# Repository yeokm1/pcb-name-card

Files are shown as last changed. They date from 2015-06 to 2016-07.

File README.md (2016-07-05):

# pcb-name-card

My name or business card that is on a Printed Circuit Board (PCB). Comes with an white LED, UV LED and a ruler. Not forgetting a QR code containing my contact details in [Vcard](https://en.wikipedia.org/wiki/VCard) format.

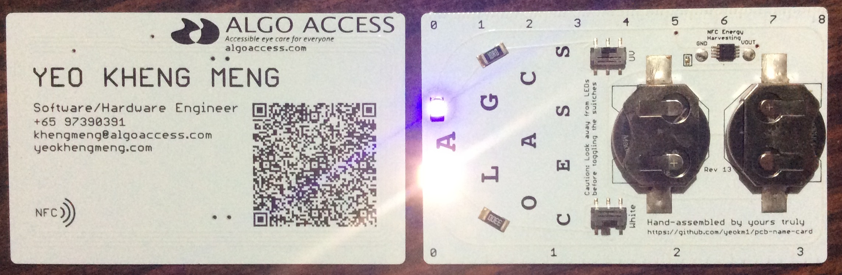
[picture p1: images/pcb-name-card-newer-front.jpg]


The lastest iteration of my name card is now in white.

I gave a talk on my name card, slides available in the picture link below.

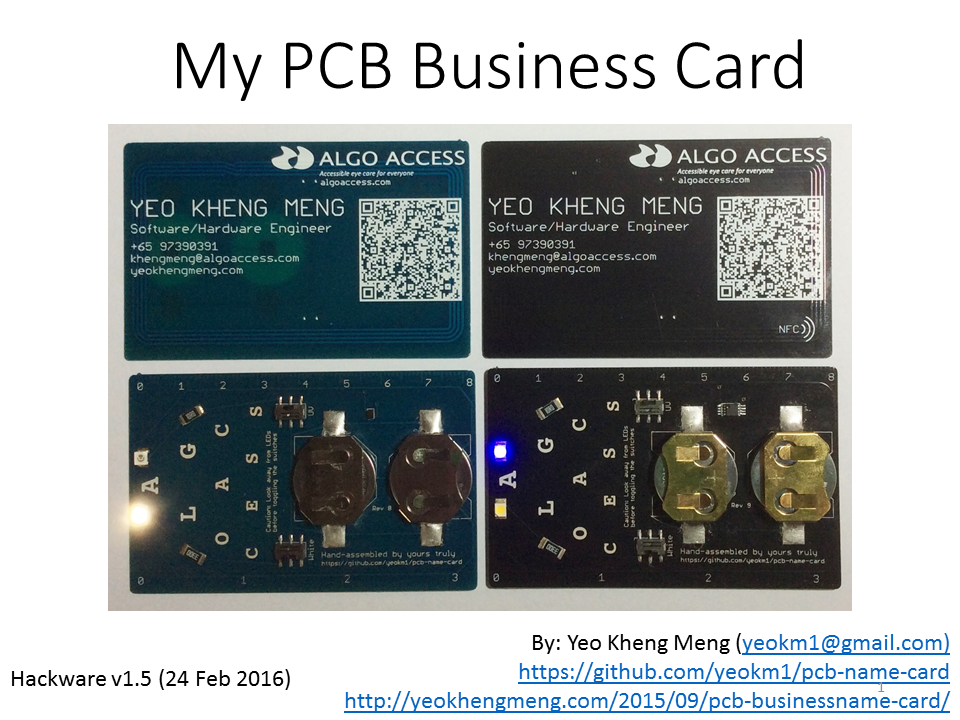
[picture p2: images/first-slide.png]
My slides on slideshare (http://www.slideshare.net/yeokm1/pcb-business-card)


###PCB Design software and addons/references used

1. Eagle 7.3.0: I use Standard but Light should still be able to open/modify the files.
2. Modified CR2032 library based on [here](https://github.com/nickaknudson/eagle-nickaknudson/blob/master/cr2032.lbr)
2. Elecrow Design Rule Check for 2 layers (in repo as `Elecrow_2-layer_eagle_rule.dru`)
3. Elecrow Gerber Generater 2-layer board (in repo as `Elecrow_Gerber_Generater_DrillAlign.cam`)
4. QR code generated from [here](http://goqr.me/)

###Schematic drawings

Images are exported from Eagle at 600dpi.

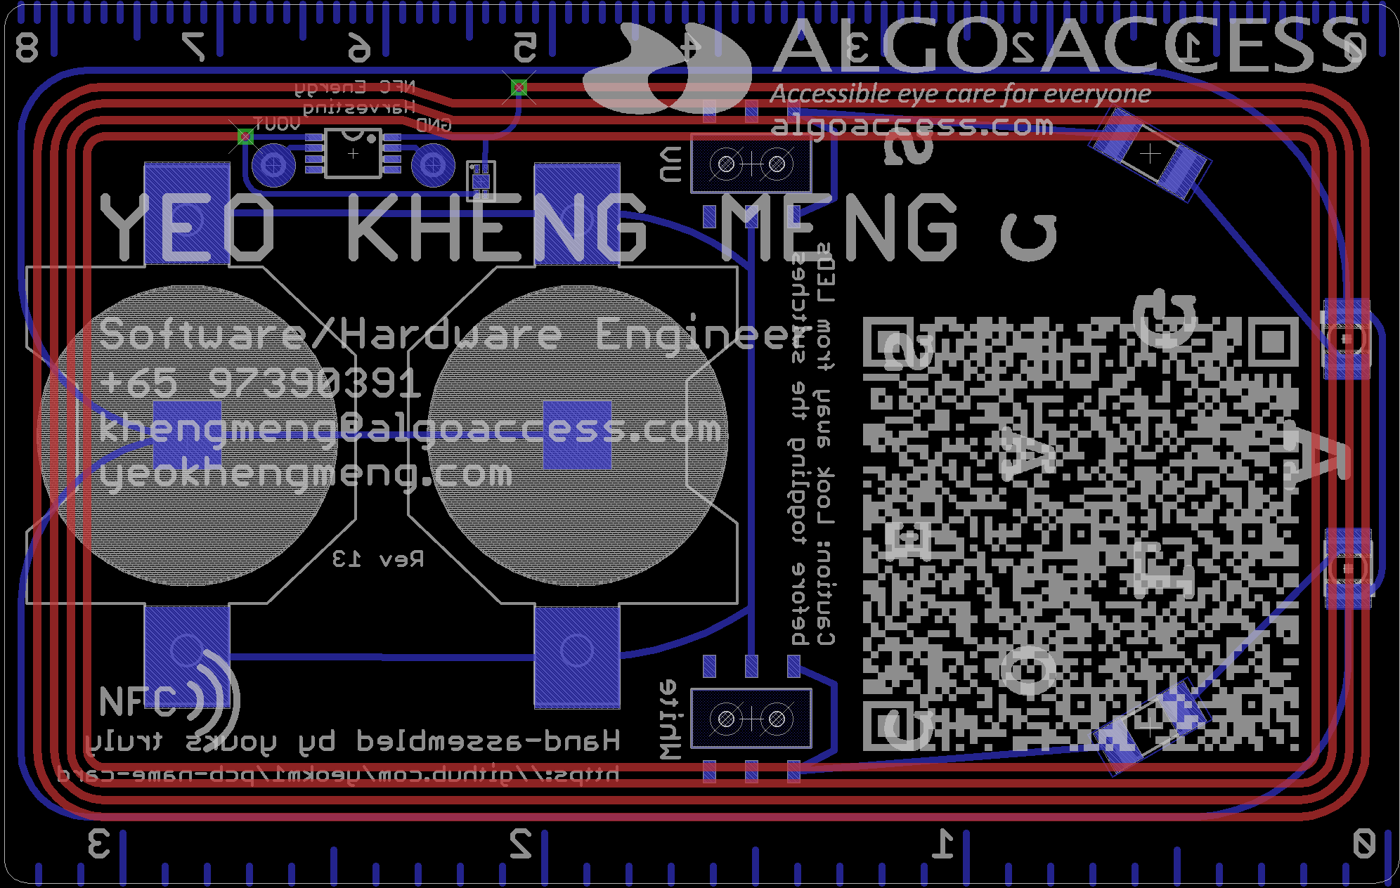
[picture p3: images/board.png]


The board layout as seen in Eagle.

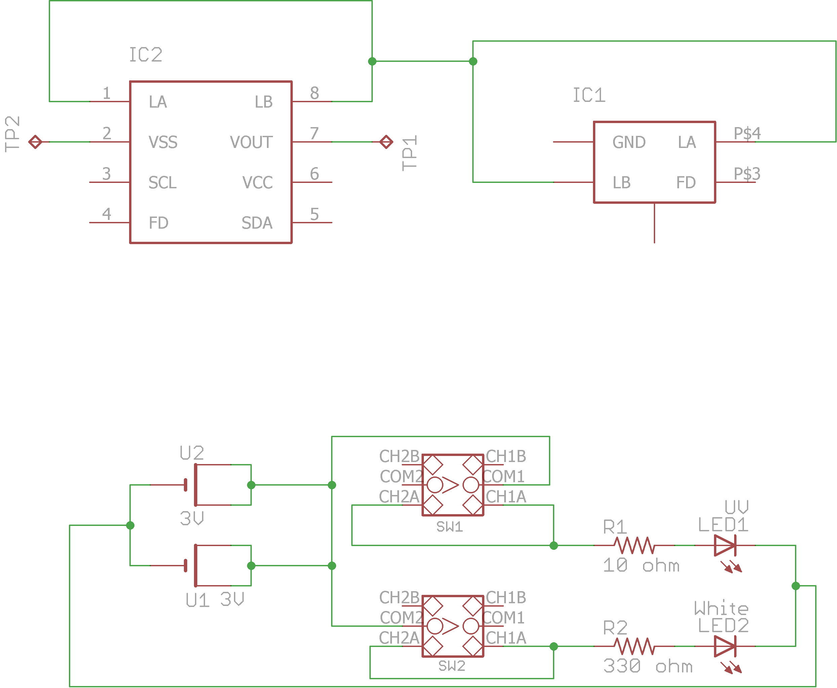
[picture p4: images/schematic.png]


The board schematic as seen in Eagle.

###Bill of Materials (BOM) for components only

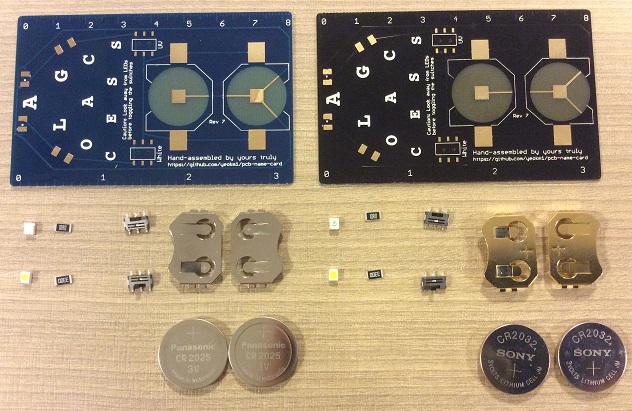
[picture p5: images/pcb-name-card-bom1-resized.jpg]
  
Components in their raw form

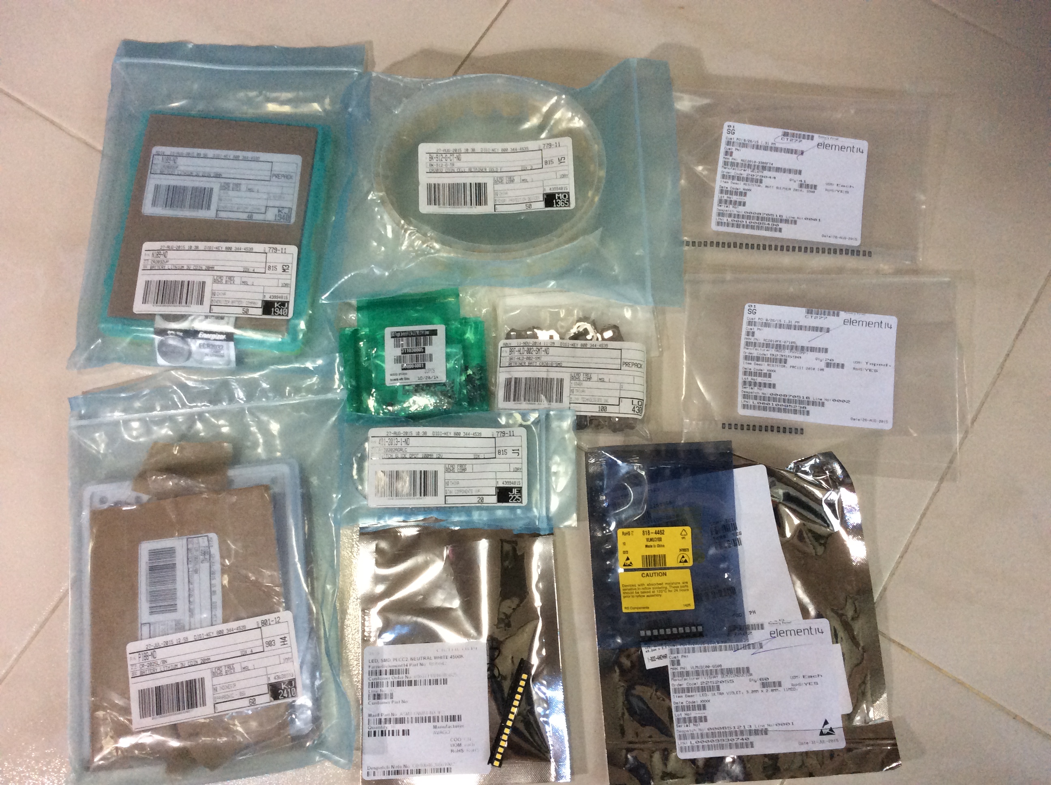
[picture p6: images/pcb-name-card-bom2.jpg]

Components still in their original packets from different suppliers.

Assume minimum order 10 pieces, cost in Singapore dollars. There are additional savings if I order more say 50 units but the savings are still small. Delivery for BOM not included.

The BOM is available in the odt spreadsheets in this repo.

###PCB fabrication

PCB fabrication is currently done by [Elecrow (10-pieces-link)](http://www.elecrow.com/10pcs-2-layer-pcb-p-1175.html) or [(50-pieces-link)](http://www.elecrow.com/50pcs-2-layer-pcb-enig-p-1172.html) based on the following settings. Remember to consult the order submission specifications at the bottom of the previous link before submitting. Use the provided Gerber generator to produce the Gerber files.

####My Fabrication Settings:

1. Layer: 2
2. PCB Thickness: 0.6mm
3. Copper Weight : 1oz 35um (NA for 50 pieces)
4. PCB Size : 10cm Max * 10cm Max (or 50cm2 for 50 pieces)
5. PCB Color : Blue or Black
6. Surface Finish: ENIG
7. PCB Stencil : NO Stencil
8. Lead time : Shipped in 4 to 7 days (NA for 50 pieces)
9. Panelizing : Single PCB with milling

###PCB Cost including delivery
Assume US$1 = SG$1.3

####Unit cost for 10 PCBs only
Total PCB Cost: US$30.80 + US$16.17 (DHL) = US$46.97  
Individual PCB Cost: (US$46.97 * 1.3) / 10 = SG$6.10  

####Unit cost for 50 PCBs only
Total PCB Cost: US$62.47 + US$18.81 (DHL) = US$81.28  
Individual PCB Cost: (US$81.28 * 1.3) / 50 = SG$2.11  

###Total Unit cost (SGD$) with components

| Pieces | Young Blue | Formal Black |
|---|---|---|
| 10 | $15.53 | $17.19 |
| 50 | $10.53 | $12.26 |

#References
1. [How to design a 13.56 MHz
customized tag antenna](http://www.st.com/st-web-ui/static/active/jp/resource/technical/document/application_note/CD00221490.pdf)
2. [The impact of high pulse drain on CR2032 coin-cell battery capacity](http://m.eet.com/media/1121454/c0924post.pdf)
3. [Panasonic NFC Design Navigator](http://www.semicon.panasonic.co.jp/en/tool/nfcdesignnavigator/)

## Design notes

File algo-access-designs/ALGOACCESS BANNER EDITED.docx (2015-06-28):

A

L G

O A C

C E S S

ALGO ACCESS PTE LTD

Accessible Eyecare for everyone

WEBSITE: www.algoaccess.com

EMAIL: info@algoaccess.com

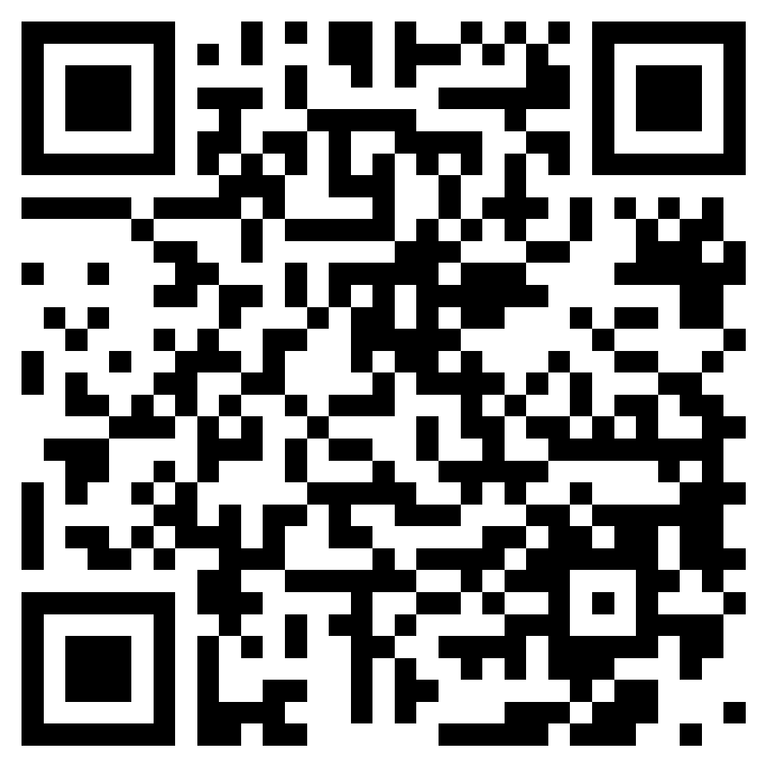
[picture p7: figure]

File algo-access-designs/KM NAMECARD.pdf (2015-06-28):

A
L G
O | A | C
C | E | S | S

## YEO KHENG MENG

WEBSITE: WWW.ALGOACCESS.COM EMAIL: KHENGMENG@ALGOACCESS.COM CONTACT NUMBER: +65 97390391

Accessible(eye(care(for(everyone(

ALGO ACCESS

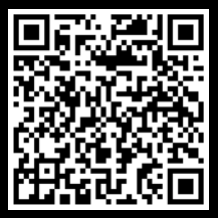
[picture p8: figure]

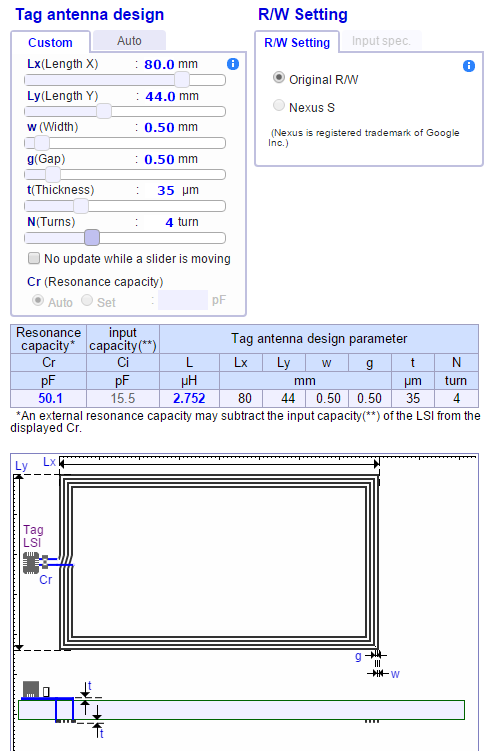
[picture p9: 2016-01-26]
images/tag-antenna-design.PNG

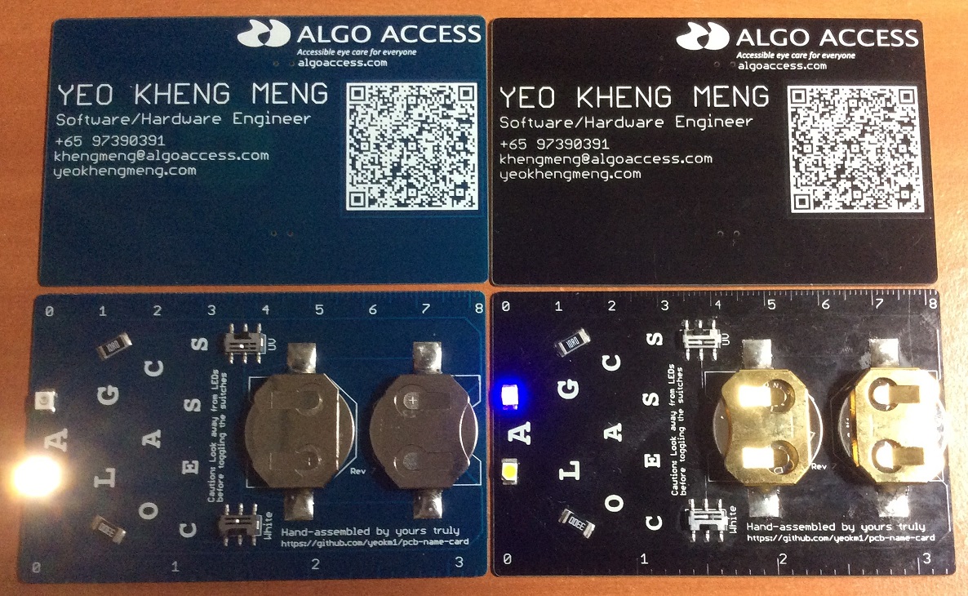
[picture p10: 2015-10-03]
images/pcb-name-card-main-resized.jpg

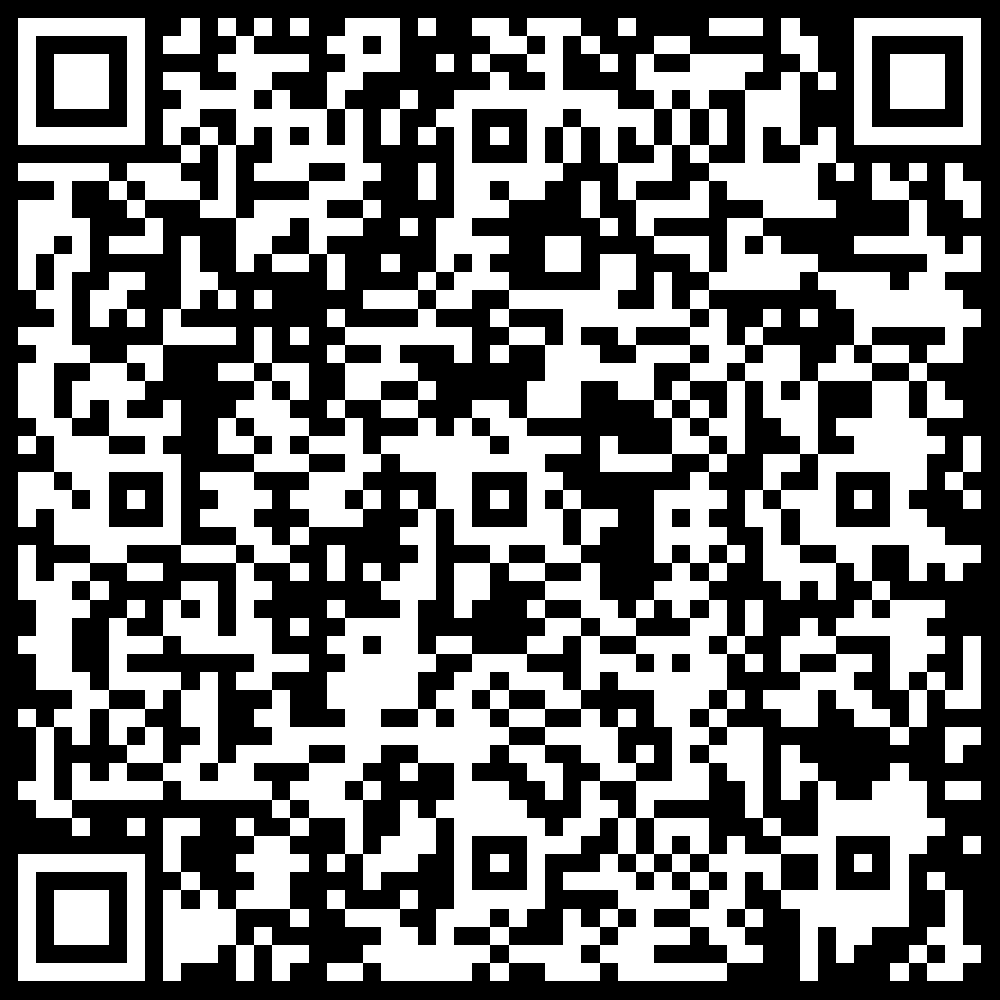
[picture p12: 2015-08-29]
algo-access-designs/qr-code-short/qr_khengmeng_inverted.bmp

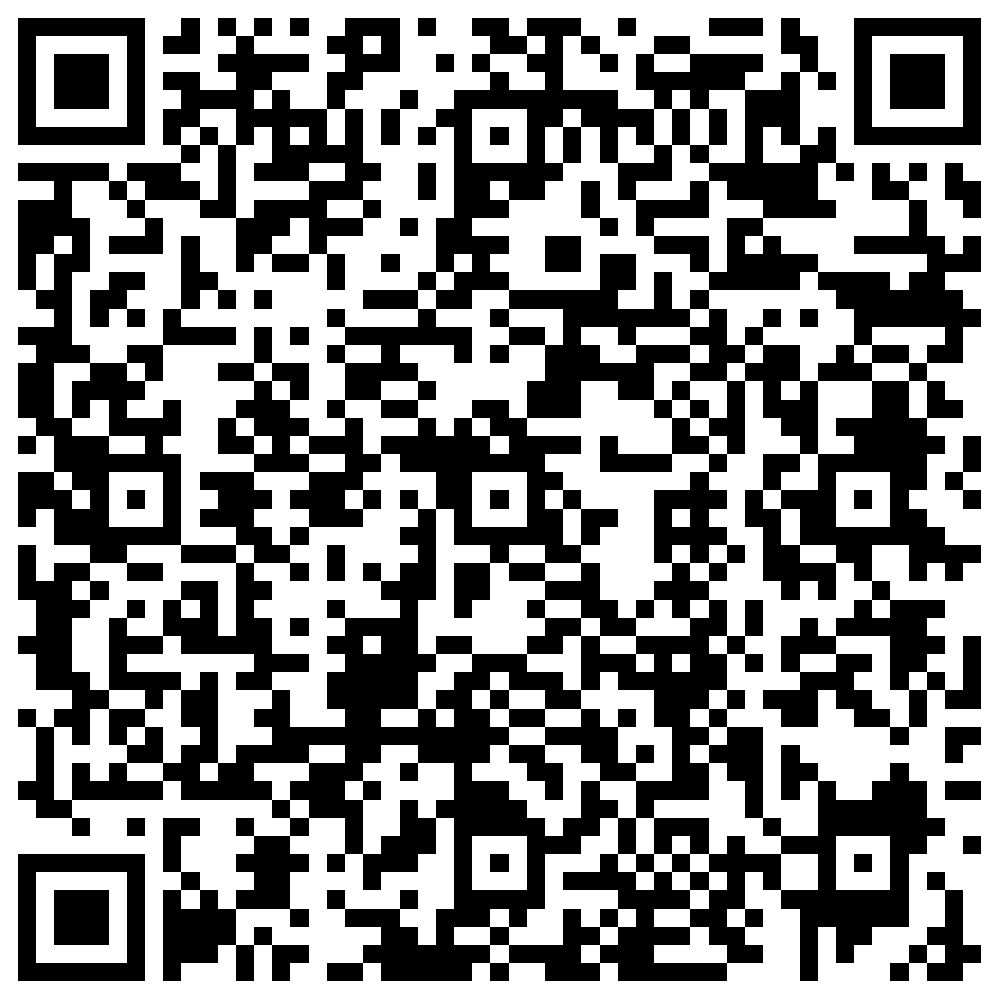
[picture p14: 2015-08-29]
algo-access-designs/qr-code-short/qr_khengmeng.png

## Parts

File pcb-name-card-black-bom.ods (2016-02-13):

Part | Value | Device | Package | Manufacturer | Part number | Quantity | Unit Cost (10) | Total Unit Cost (10) | Unit Cost (50) | Total Unit Cost (50) | Source webpage
LED1 | UV | UV SMD LED | PLCC2 | Vishay | VLMU3100-GS08 | 1 | 0.469 | 0.469 | 0.469 | 0.469 | https://sg.rs-online.com/web/p/uv-leds/8184462/
LED2 | Neutral White | White SMD LED | PLCC2 | Avago Technologies | ASMT-UWB1-NX3E2 | 1 | 0.552 | 0.552 | 0.552 | 0.552 | http://sg.element14.com/avago-technologies/asmt-uwb1-nx3e2/led-smd-plcc2-neutral-white-4500k/dp/1895842
R1 | 10 ohm, ±1% | Surface Mount Chip Resistor, Thick Film, RC Series | R2010 | Yageo (Phycomp) | RC2010FK-0710RL | 1 | 0.228 | 0.228 | 0.228 | 0.228 | http://sg.element14.com/yageo-phycomp/rc2010fk-0710rl/resistor-prc111-2010-10r/dp/9235590
R2 | 330 ohm, ±1% | Surface Mount Chip Resistor, Thick Film, ASC Series | R2010 | Welwyn | ASC2010-330RFT4 | 1 | 0.149 | 0.149 | 0.149 | 0.149 | http://sg.element14.com/welwyn/asc2010-330rft4/resistor-anti-sulphur-2010-330r/dp/2079044
SW1, SW2 | - | Slide Switch, DPDT, Vertical, SMD | SW6-2.54-SMD-7.0X3.5X1.5MM | C & K Components | AYZ0202AGRLC | 2 | 2.07 | 4.14 | 1.81 | 3.62 | http://sg.element14.com/c-k-components/ayz0202agrlc/switch-dpdt-0-1a-12vdc-smd-on/dp/2319973
U1, U2 | 3V | CR2032 battery gold battery retainer | SMD holder | Memory Protection Devices | BK-912-G-TR | 2 | 0.934 | 1.868 | 0.934 | 1.868 | http://www.digikey.sg/product-detail/en/0/BK-912-G-CT-ND
IC1 | 888 bytes | NTAG216 | HXSON-4 | NXP | NT2H1611F0DTLH | 0 | 1.15 | 0 | 1.15 | 0 | http://www.mouser.sg/Search/ProductDetail.aspx?R=NT2H1611F0DTLH
IC2 | 1904 bytes | NTAG I2C | TSSOP-8 | NXP | NT3H1201W0FTTJ | 1 | 1.63 | 1.63 | 1.63 | 1.63 | http://www.mouser.sg/Search/ProductDetail.aspx?R=NT3H1201W0FTTJ
- | 3V | CR2032 battery | CR2032 | Energizer | CR2032VP | 2 | 0.467 | 0.934 | 0.415 | 0.83 | http://www.digikey.sg/product-detail/en/0/N189-ND
- | ENIG, Black | PCB manufacturing cost without stencil | 10cm x 10cm, 0.6mm thickness | Elecrow | - | 1 | 6.1 | 6.1 | 2.11 | 2.11 | http://www.elecrow.com/10pcs-2-layer-pcb-p-1175.html | http://www.elecrow.com/50pcs-2-layer-pcb-enig-p-1172.html
 |  |  |  |  |  |  | Subtotal | 16.07 |  | 11.456
 |  |  |  |  |  |  | GST 7% | 1.1249 |  | 0.80192
 |  |  |  |  |  |  | Total (SGD) | 17.1949 |  | 12.25792

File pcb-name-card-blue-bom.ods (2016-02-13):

Part | Value | Device | Package | Manufacturer | Part number | Quantity | Unit Cost (10) | Total Unit Cost (10) | Unit Cost (50) | Total Unit Cost (50) | Source webpage
LED1 | UV | UV SMD LED | PLCC2 | Vishay | VLMU3100-GS08 | 1 | 0.469 | 0.469 | 0.469 | 0.469 | https://sg.rs-online.com/web/p/uv-leds/8184462/
LED2 | Neutral White | White SMD LED | PLCC2 | Avago Technologies | ASMT-UWB1-NX3E2 | 1 | 0.552 | 0.552 | 0.552 | 0.552 | http://sg.element14.com/avago-technologies/asmt-uwb1-nx3e2/led-smd-plcc2-neutral-white-4500k/dp/1895842
R1 | 10 ohm, ±1% | Surface Mount Chip Resistor, Thick Film, RC Series | R2010 | Yageo (Phycomp) | RC2010FK-0710RL | 1 | 0.228 | 0.228 | 0.228 | 0.228 | http://sg.element14.com/yageo-phycomp/rc2010fk-0710rl/resistor-prc111-2010-10r/dp/9235590
R2 | 330 ohm, ±1% | Surface Mount Chip Resistor, Thick Film, ASC Series | R2010 | Welwyn | ASC2010-330RFT4 | 1 | 0.149 | 0.149 | 0.149 | 0.149 | http://sg.element14.com/welwyn/asc2010-330rft4/resistor-anti-sulphur-2010-330r/dp/2079044
SW1, SW2 | - | Slide Switch, DPDT, Vertical, SMD | SW6-2.54-SMD-7.0X3.5X1.5MM | C & K Components | AYZ0202AGRLC | 2 | 2.07 | 4.14 | 1.81 | 3.62 | http://sg.element14.com/c-k-components/ayz0202agrlc/switch-dpdt-0-1a-12vdc-smd-on/dp/2319973
U1, U2 | 3V | CR2016 battery retainer (works for CR2025) | SMD holder | Linx Technologies Inc | BAT-HLD-002-SMT | 2 | 0.43 | 0.86 | 0.398 | 0.796 | http://www.digikey.sg/product-detail/en/0/BAT-HLD-002-SMT-ND
IC1 | 888 bytes | NTAG216 | HXSON-4 | NXP | NT2H1611F0DTLH | 1 | 1.15 | 1.15 | 1.15 | 1.15 | http://www.mouser.sg/Search/ProductDetail.aspx?R=NT2H1611F0DTLH
IC2 | 1904 bytes | NTAG I2C | TSSOP-8 | NXP | NT3H1201W0FTTJ | 0 | 1.63 | 0 | 1.63 | 0 | http://www.mouser.sg/Search/ProductDetail.aspx?R=NT3H1201W0FTTJ
- | 3V | CR2025 battery | CR2025 | Panasonic – BSG | CR-2025L/BN | 2 | 0.431 | 0.862 | 0.383 | 0.766 | http://www.digikey.sg/product-detail/en/0/P188-ND
- | ENIG, Blue | PCB manufacturing cost without stencil | 10cm x 10cm, 0.6mm thickness | Elecrow | - | 1 | 6.1 | 6.1 | 2.11 | 2.11 | http://www.elecrow.com/10pcs-2-layer-pcb-p-1175.html | http://www.elecrow.com/50pcs-2-layer-pcb-enig-p-1172.html
 |  |  |  |  |  |  | Subtotal | 14.51 |  | 9.84
 |  |  |  |  |  |  | GST 7% | 1.0157 |  | 0.6888
 |  |  |  |  |  |  | Total (SGD) | 15.5257 |  | 10.5288

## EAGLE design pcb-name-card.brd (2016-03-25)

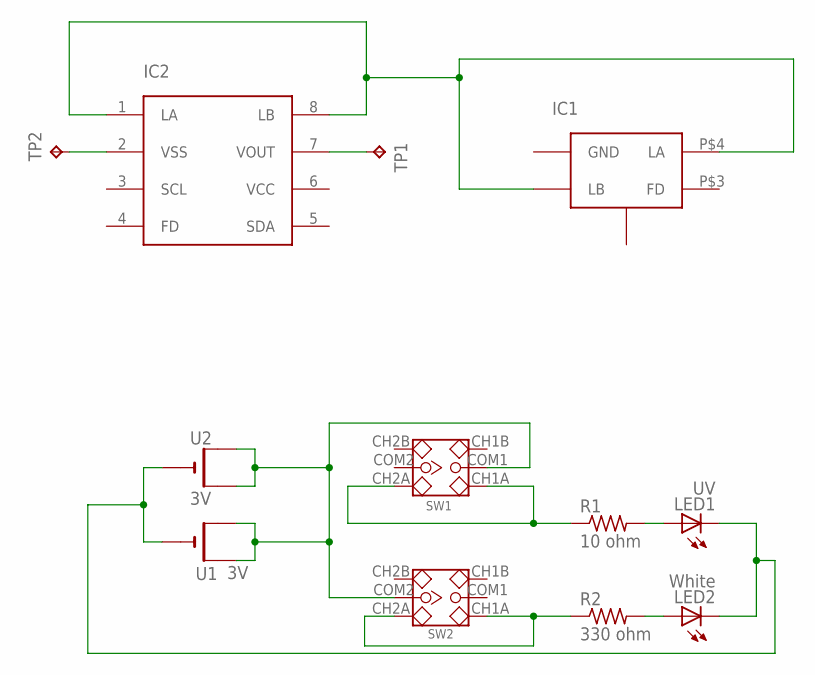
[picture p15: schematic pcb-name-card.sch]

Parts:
IC1: NTAG21XFDRC-FIT; HXSON4-SMALL
IC2: NT3H1X01W0FTT; TSSOP-8
LED1: UV; PLCC2
LED2: White; PLCC2
R1: 10 ohm; R2010
R2: 330 ohm; R2010
SW1, SW2: SMD-TOGGLE-SWITCH-2CH(2X3P-7X3.5MM); SW6-2.54-SMD-7.0X3.5X1.5MM
TP1: VOUT; B2,54
TP2: GND; B2,54
U1, U2: 3V; CR2032-SMD

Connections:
unnamed: LED1.A, R1.2
unnamed: LED2.A, R2.2
unnamed: R1.1, SW1.CH1A, SW1.CH2A
unnamed: R2.1, SW2.CH1A, SW2.CH2A
unnamed: IC1.P$2 (LB), IC1.P$4 (LA), IC2.1 (LA), IC2.8 (LB)
unnamed: LED1.C, LED2.C, U1.-, U2.-
unnamed: SW1.COM1, SW2.COM2, U1.+$1 (+), U1.+$2 (+1), U2.+$1 (+), U2.+$2 (+1)
unnamed: IC2.2 (VSS), TP2.TP
unnamed: IC2.7 (VOUT), TP1.TP

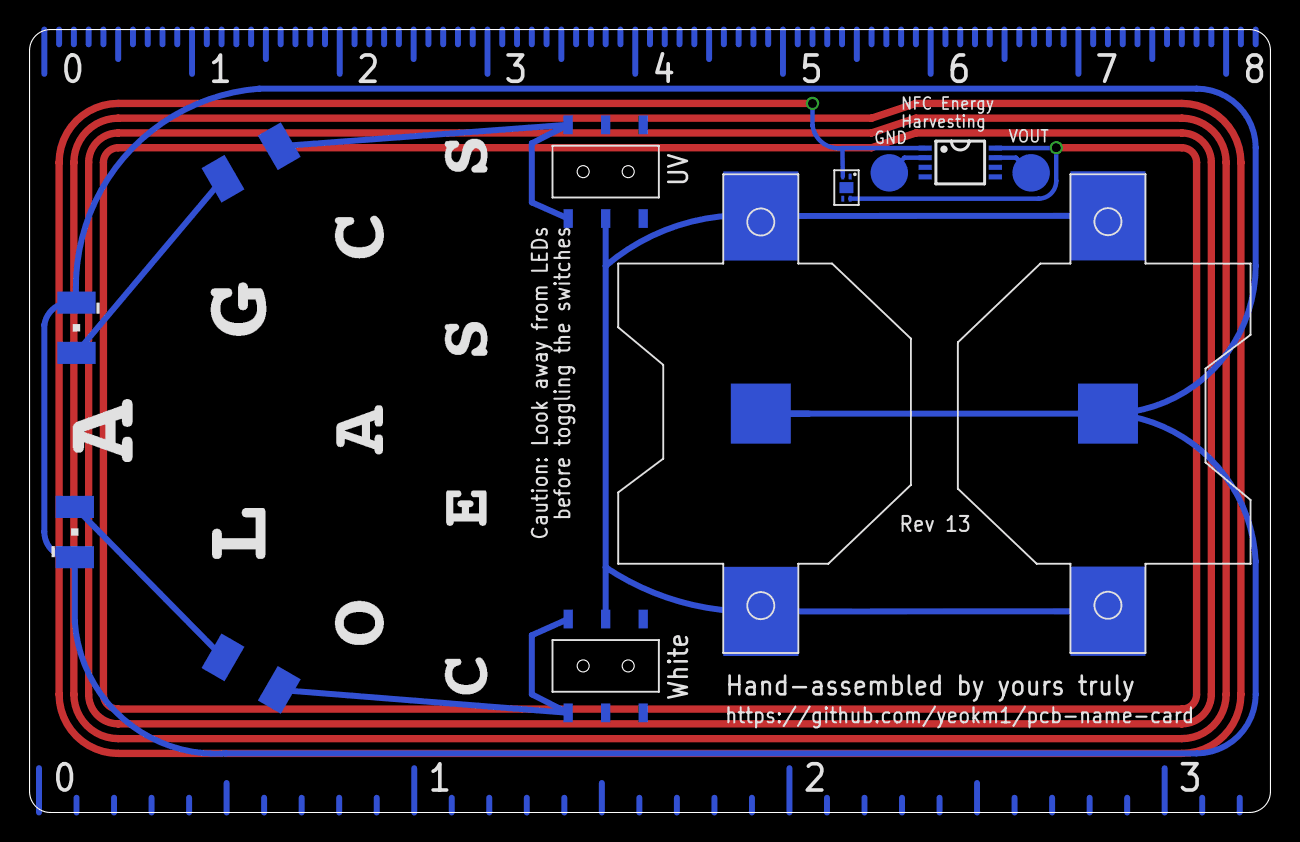
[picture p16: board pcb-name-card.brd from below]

Board: 2 copper layers, 84.0 x 53.0 mm, 12 parts (12 on the bottom side), 9 nets.

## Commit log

2015-06-28 aa banner
    [pcb-name-card.brd]
2015-06-28 more changes
    [pcb-name-card.brd, pcb-name-card.sch]
2015-06-28 some changes
    [pcb-name-card.brd]
2015-06-28 some updates
    [pcb-name-card.brd]
2015-06-28 reimport qr code
    [pcb-name-card.brd]
2015-06-28 qr code
    [pcb-name-card.brd]
2015-06-28 all items in
    [pcb-name-card.brd]
2015-06-28 cm ruler
    [pcb-name-card.brd]
2015-06-28 inch ruler
    [pcb-name-card.brd]
2015-06-28 add personal website in text
    [pcb-name-card.brd]
2015-06-28 new qr code image
    [pcb-name-card.brd]
2015-06-28 + - signs around led
    [pcb-name-card.brd]
2015-06-28 revision 2 begins
    [pcb-name-card.brd]
2015-06-28 rev 2
    [pcb-name-card.brd]
2015-06-29 remove name of qr code
    [pcb-name-card.brd]
2015-07-28 vector font
    [pcb-name-card.brd]
2015-07-28 remove labels
    [pcb-name-card.brd]
2015-07-28 extra wiring
    [pcb-name-card.brd]
2015-07-28 miter edges
    [pcb-name-card.brd]
2015-07-28 hand assembly text
    [pcb-name-card.brd]
2015-07-28 hand assembled by yours truly
    [pcb-name-card.brd]
2015-07-28 alignment issues
    [pcb-name-card.brd]
2015-07-29 change label position
    [pcb-name-card.brd]
2015-07-29 view all
    [pcb-name-card.brd]
2015-08-04 rev 3. one line on top layer so PCB manufacturers don't give me issue about missing top layer
    [pcb-name-card.brd]
2015-08-05 larger positive battery contacts
    [pcb-name-card.brd, pcb-name-card.sch]
2015-08-05 battery position
    [pcb-name-card.brd]
2015-08-05 see top layer
    [pcb-name-card.brd]
2015-08-05 make trace straighter
    [pcb-name-card.brd]
2015-08-18 remove battery text
    [pcb-name-card.brd]
2015-08-18 some text changes
    [pcb-name-card.brd]
2015-08-18 shift some stuff forward by 1mm
    [pcb-name-card.brd]
2015-08-18 top square around QR code
    [pcb-name-card.brd]
2015-08-18 make square around qr code larger
    [pcb-name-card.brd]
2015-08-24 rev 5 switch position
    [pcb-name-card.brd]
2015-08-29 reduce size of schematic
    [pcb-name-card.sch]
2015-08-29 board images
2015-08-29 shift white led abit
    [pcb-name-card.brd]
2015-08-29 mitre edges further
    [pcb-name-card.brd]
2015-08-29 rev 6 board.png
2015-08-29 add extra redundant wire for ground
    [pcb-name-card.brd]
2015-08-29 change qr code
    [pcb-name-card.brd]
2015-08-29 details shift down
    [pcb-name-card.brd]
2015-08-29 change phone number to +65
    [pcb-name-card.brd]
2015-08-30 adjusted redundant ground wire around led
    [pcb-name-card.brd]
2015-08-31 change developer to engineer
    [pcb-name-card.brd]
2015-08-31 board png
2015-09-11 shift bottom text
    [pcb-name-card.brd]
2015-09-11 shift battery a little back
    [pcb-name-card.brd]
2015-09-11 up to rev 7
    [pcb-name-card.brd]
2015-09-11 new rev 7 board image
2015-09-14 add missing 3 inch marking
    [pcb-name-card.brd]
2015-10-03 update to rev 7 pcb images
2015-12-11 move to standard folders
    [pcb-name-card-bom.ods]
2015-12-11 bom in spreadsheet
    [pcb-name-card-black-bom.ods, pcb-name-card-blue-bom.ods]
2015-12-11 remove old BOM file
    [pcb-name-card-bom.ods]
2016-01-15 adjust formatting
    [pcb-name-card-black-bom.ods, pcb-name-card-blue-bom.ods]
2016-01-26 support nfc band
    [pcb-name-card.brd, pcb-name-card.sch]
2016-01-27 shift warning text back up
    [pcb-name-card.brd]
2016-01-27 rev8 pcb with ntag216
2016-01-27 use ntag i2c
    [pcb-name-card.brd, pcb-name-card.sch]
2016-01-27 nfc logo
    [pcb-name-card.brd]
2016-01-27 adjusted ruler labels
    [pcb-name-card.brd]
2016-01-27 redundant ground wire
    [pcb-name-card.brd]
2016-01-27 view layer
    [pcb-name-card.brd]
2016-02-03 adjust S silkscreen pos
    [pcb-name-card.brd]
2016-02-04 adjusted size of ntag i2c
    [pcb-name-card.brd, pcb-name-card.sch]
2016-02-04 combine both tag footprints on design
    [pcb-name-card.brd, pcb-name-card.sch]
2016-02-04 adjust ntag21xf lbr to make pin 1 dot bigger
    [pcb-name-card.brd, pcb-name-card.sch]
2016-02-04 add curvature to NFC wires
    [pcb-name-card.brd]
2016-02-12 NFC harvesting test points
    [pcb-name-card.brd, pcb-name-card.sch]
2016-02-12 rev 10 gerber
2016-02-12 rename gerber directory
2016-02-13 update BOM with NFC chips
    [pcb-name-card-black-bom.ods, pcb-name-card-blue-bom.ods]
2016-03-07 adjusted silkscreen and some wiring pos
    [pcb-name-card.brd]
2016-03-07 qr code uses extended version and assumes black silkscreen on white soldermask
    [pcb-name-card.brd]
2016-03-14 adjusted font thickness and silkscreen positions
    [pcb-name-card.brd]
2016-03-14 some adjustments
    [pcb-name-card.brd]
2016-03-14 rev12 gerber
2016-03-25 increase font ratio to 14%
    [pcb-name-card.brd]
2016-07-05 newer pcb name card image
